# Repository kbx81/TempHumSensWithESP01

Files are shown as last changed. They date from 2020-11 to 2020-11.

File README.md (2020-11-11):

# kbx's Temperature and Humidity Sensor Board for ESP-01

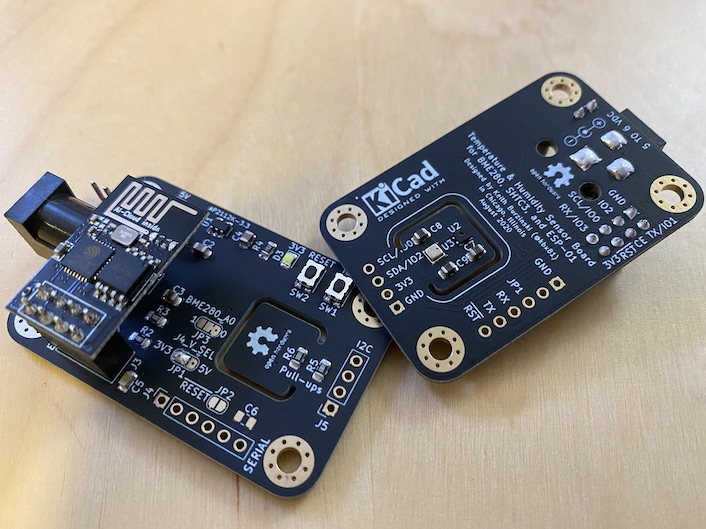
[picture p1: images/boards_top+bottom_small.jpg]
TempHumSensWithESP01


## What?

Just another environmental sensor board to plug an ESP-01 module onto.
 It was designed with [ESPHome](https://esphome.io) in mind but should work fine
 with [Tasmota](https://tasmota.github.io/docs/) or any other app, really.

## Why?

I needed a sensor board to monitor the humidity in my filament storage box.
 I was somewhat unhappy with the tiny DHT22 boards that are typically available
 on Amazon and elsewhere so I spun my own version. The dual-sensor arrangement
 allows for some redundancy -- they, in a sense, verify each other to help
 increase confidence in the readings/data they provide.

The board itself is sized to align with extra mounting holes that seem to be
 in the Prusa MK3 frame. With the help of the [spacer](BME280+SHTC3BoardMountForPrusaMK3.stl)
 I drew up, it should be possible to mount it directly to the printer's frame
 with just two M3 screws from your "spare parts" baggy. I've done this to monitor
 the temperature inside of the LACK enclosure I built for my printer with the help
 of [Home Assistant](https://www.home-assistant.io), [ESPHome](https://esphome.io)
 and [Grafana](https://grafana.com). This board can be powered from a spare 5-volt
 header that's near the top of the MK3's RAMbo board (the cable is visible in the
 pictures I've placed into the [images](images/) directory).

## How?

Please see the BoM [here](TempHumSensWithESP01.bom.csv) or
 [here](https://octopart.com/bom-tool/L01oa2CK) for a list of parts needed to
 build one. I had the PCBs fabricated by [Elecrow](https://www.elecrow.com) but
 nearly any PCB fabricator should be able to manufacture these without any issues.

The schematic and PCB were drawn in [KiCAD](https://www.kicad-pcb.org).

The BME280 is the most challenging part on this board -- the pads are on the
 underside of the device. You'll need a steady hand and either a hot air station
 or a reflow oven to solder this part to the board. The rest of the components are
 pretty easy to work with.

Note that `R7` is optional; you can use it as a pull-up resistor in the event that
 you'd like to connect a DHTxx module to the RX/GPIO3 line on the ESP-01. Why?
 Because more sensors...duh...

 ## Legal stuff and License

The circuit schematics and PCB found here are licensed under the
 [Creative Commons Attribution-ShareAlike 4.0 International License](http://creativecommons.org/licenses/by-sa/4.0/).



_Happy building!_

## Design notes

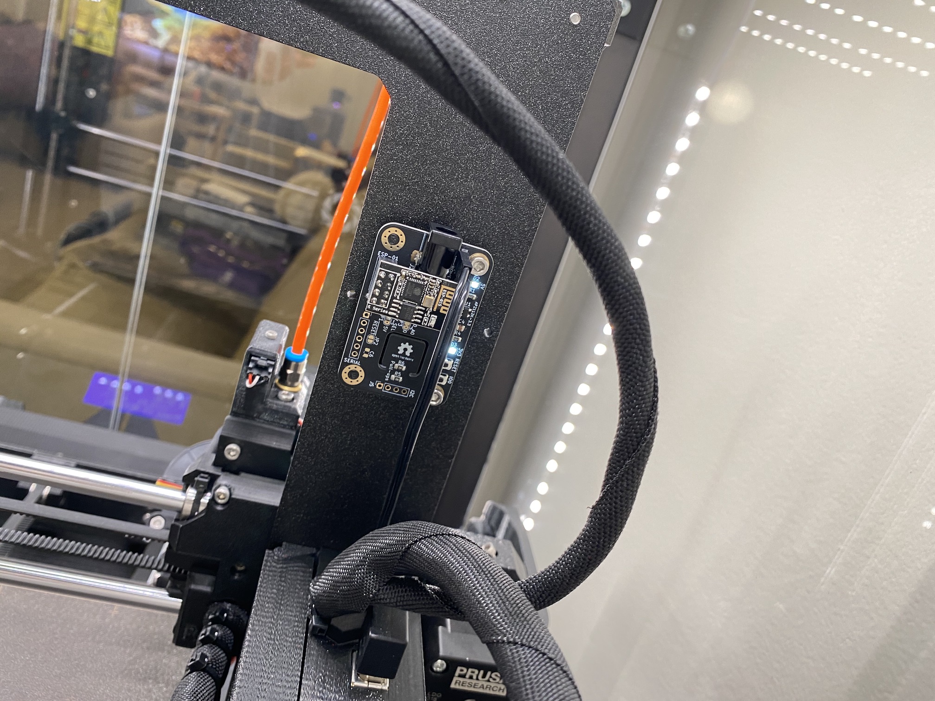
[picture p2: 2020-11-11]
images/board_on_mk3.jpg

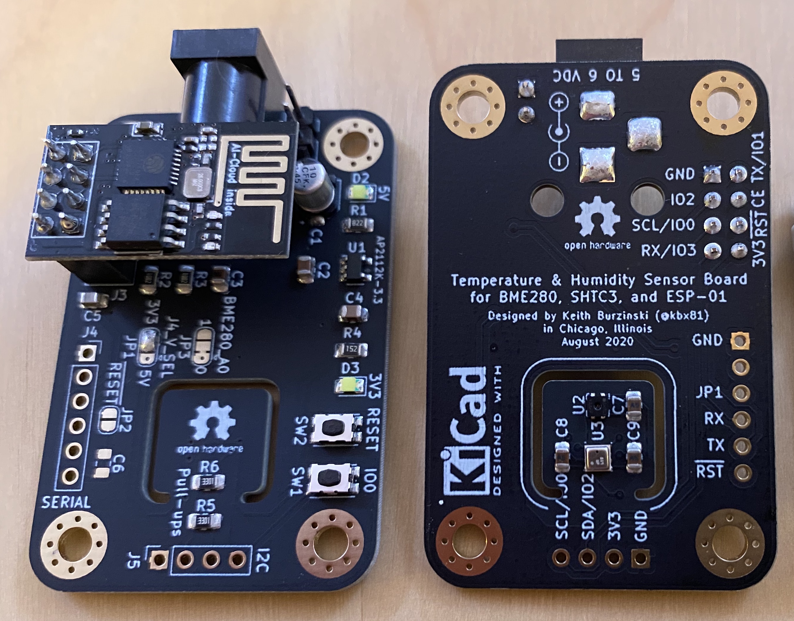
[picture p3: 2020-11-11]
images/boards_flat_top+bottom.jpg

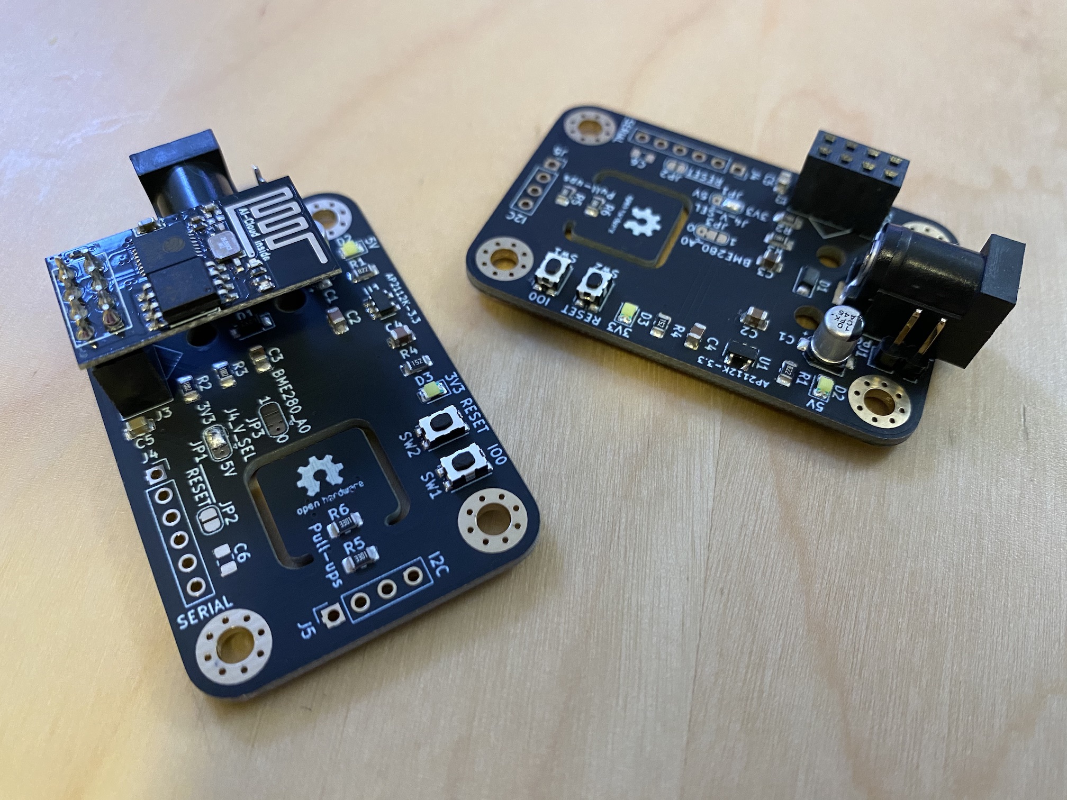
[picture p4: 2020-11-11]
images/boards_top.jpg

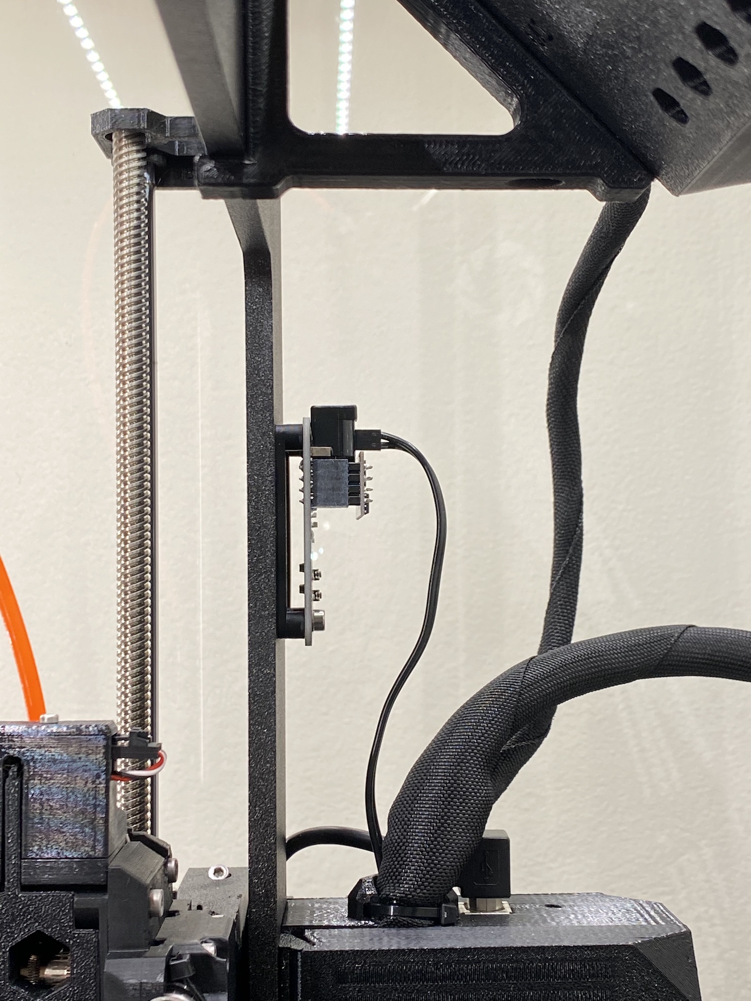
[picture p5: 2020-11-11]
images/board_on_mk3_side.jpg

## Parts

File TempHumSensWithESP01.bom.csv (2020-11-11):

Item | Qty | Reference(s) | Value | LibPart | Footprint | Datasheet | Part
1 | 1 | C1 | 10 uF | Device:CP | Capacitor_SMD:CP_Elec_4x5.8 | https://www.cde.com/resources/catalogs/AFK.pdf | AFK106M16B12T-F
2 | 2 | C2, C4 | 1 uF | Device:C | Capacitor_SMD:C_0805_2012Metric | ~ | CGA4J2X7R1C105K125AA
3 | 5 | C3, C6, C7, C8, C9 | 100 nF | Device:C | Capacitor_SMD:C_0805_2012Metric | ~ | CC0805KRX7R7BB104
4 | 1 | C5 | 10 uF | Device:C | Capacitor_SMD:C_0805_2012Metric | ~ | C2012X5R1C106M085AC
5 | 1 | D1 | MBR120 | Device:D_Schottky | Diode_SMD:D_SOD-123 | ~ | MBR120
6 | 1 | D2 | 5V | Device:LED | LED_SMD:LED_0805_2012Metric | ~ | LSM0805543V
7 | 1 | D3 | 3V3 | Device:LED | LED_SMD:LED_0805_2012Metric | ~ | LSM0805543V
11 | 1 | J2 | 5 TO 6 VDC | Connector:Barrel_Jack_Switch | Connector_BarrelJack:BarrelJack_Horizontal | ~ | 694106301002
18 | 1 | R1 | 8K2 | Device:R | Resistor_SMD:R_0805_2012Metric_Pad1.15x1.40mm_HandSolder | ~ | RT0805FRE078K2L
19 | 3 | R2, R3, R7 | 10K | Device:R | Resistor_SMD:R_0805_2012Metric_Pad1.15x1.40mm_HandSolder | ~ | RC0805FR-0710KL
20 | 1 | R4 | 1K6 | Device:R | Resistor_SMD:R_0805_2012Metric_Pad1.15x1.40mm_HandSolder | ~ | RT0805FRE071K6L
21 | 2 | R5, R6 | 3K3 | Device:R | Resistor_SMD:R_0805_2012Metric_Pad1.15x1.40mm_HandSolder | ~ | RT0805FRE073K3L
22 | 1 | SW1 | IO0 | Switch:SW_Push | Button_Switch_SMD:SW_Push_1P1T_NO_CK_KMR2 | ~ | KMR221GLFS
23 | 1 | SW2 | RESET | Switch:SW_Push | Button_Switch_SMD:SW_Push_1P1T_NO_CK_KMR2 | ~ | KMR221GLFS
24 | 1 | U1 | AP2112K-3.3 | Regulator_Linear:AP2112K-3.3 | Package_TO_SOT_SMD:SOT-23-5 | https://www.diodes.com/assets/Datasheets/AP2112.pdf | AP2112K-3.3TRG1
25 | 1 | U2 | SHTC3 | Sensor_Humidity:SHTC3 | Package_DFN_QFN:AMS_QFN-4-1EP_2x2mm_P0.95mm_EP0.7x1.6mm | https://www.sensirion.com/fileadmin/user_upload/customers/sensirion/Dokumente/0_Datasheets/Humidity/Sensirion_Humidity_Sensors_SHT1x_Datasheet.pdf | SHTC3
26 | 1 | U3 | BME280 | Sensor:BME280 | Package_LGA:Bosch_LGA-8_2.5x2.5mm_P0.65mm_ClockwisePinNumbering | https://ae-bst.resource.bosch.com/media/_tech/media/datasheets/BST-BME280-DS002.pdf | BME280

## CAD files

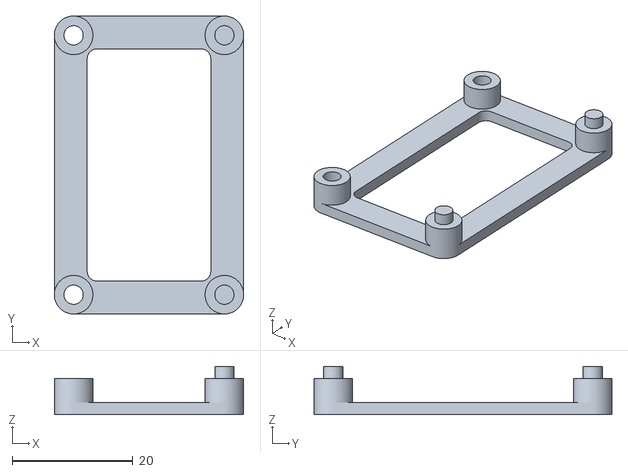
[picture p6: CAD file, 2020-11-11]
BME280+SHTC3BoardMountForPrusaMK3.stl
31.4 x 49.4 x 8.00

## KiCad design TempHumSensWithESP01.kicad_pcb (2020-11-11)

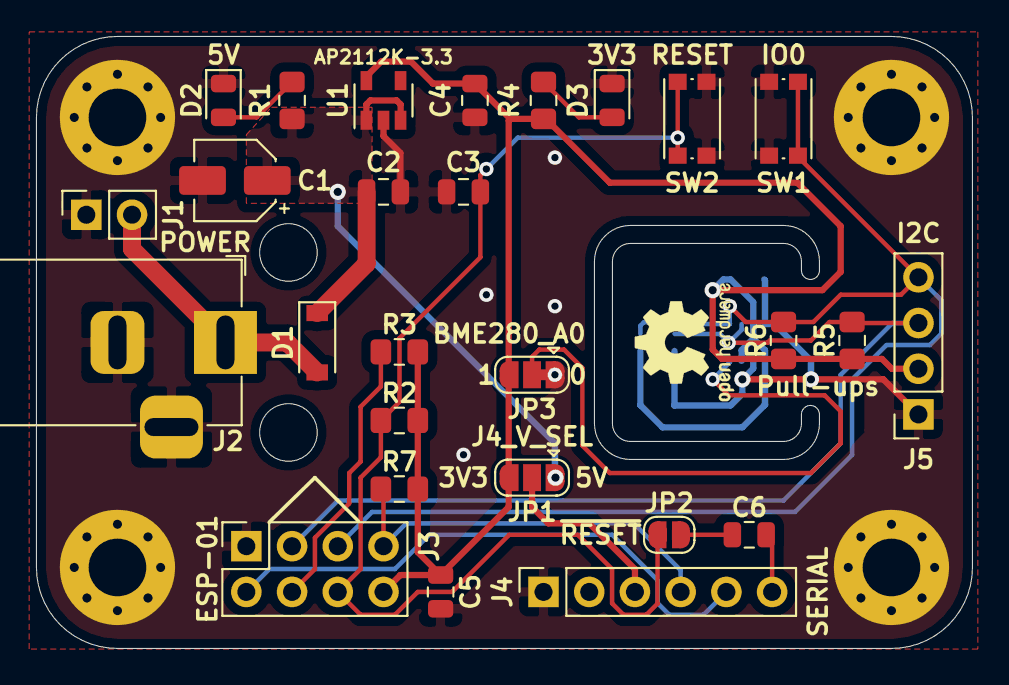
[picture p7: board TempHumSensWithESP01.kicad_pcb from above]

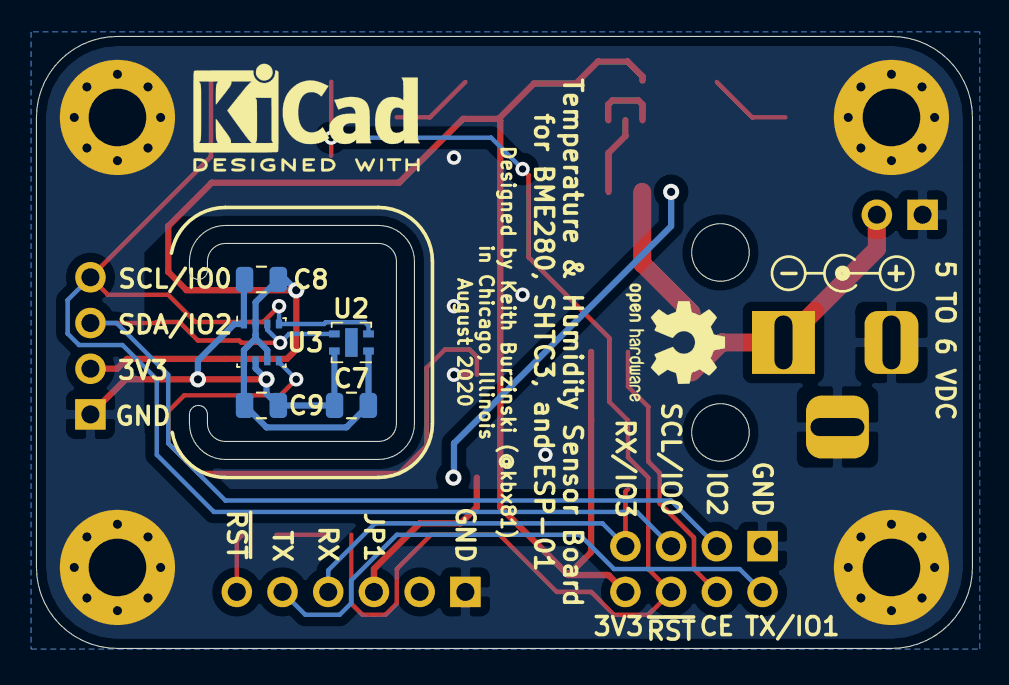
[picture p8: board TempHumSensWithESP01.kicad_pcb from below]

Board: 2 copper layers, 52.0 x 34.0 mm, 38 parts (7 on the bottom side), 16 nets.

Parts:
C1: 10 uF; CP_Elec_4x5.8
C2, C4: 1 uF; C_0805_2012Metric
C3, C6, C7, C8, C9: 100 nF; C_0805_2012Metric
C5: 10 uF; C_0805_2012Metric
D1: MBR120; D_SOD-123
D2: 5V; LED_0805_2012Metric
D3: 3V3; LED_0805_2012Metric
H1, H2, H3, H4: MountingHole_Pad; MountingHole_3.2mm_M3_Pad_Via
H5, H6: MountingHole; MountingHole_3.2mm_M3
J1: POWER; PinSocket_1x02_P2.54mm_Vertical
J2: 5 TO 6 VDC; BarrelJack_Horizontal
J3: ESP-01; PinSocket_2x04_P2.54mm_Vertical
J4: SERIAL; PinSocket_1x06_P2.54mm_Vertical
J5: I2C; PinSocket_1x04_P2.54mm_Vertical
JP1: J4_V_SEL; SolderJumper-3_P1.3mm_Open_RoundedPad1.0x1.5mm
JP2: ~RESET; SolderJumper-2_P1.3mm_Open_RoundedPad1.0x1.5mm
JP3: BME280_A0; SolderJumper-3_P1.3mm_Bridged12_RoundedPad1.0x1.5mm
R1: 8K2; R_0805_2012Metric_Pad1.15x1.40mm_HandSolder
R2, R3, R7: 10K; R_0805_2012Metric_Pad1.15x1.40mm_HandSolder
R4: 1K6; R_0805_2012Metric_Pad1.15x1.40mm_HandSolder
R5, R6: 3K3; R_0805_2012Metric_Pad1.15x1.40mm_HandSolder
SW1: IO0; SW_Push_1P1T_NO_CK_KMR2
SW2: RESET; SW_Push_1P1T_NO_CK_KMR2
U1: AP2112K-3.3; SOT-23-5
U2: SHTC3; AMS_QFN-4-1EP_2x2mm_P0.95mm_EP0.7x1.6mm
U3: BME280; Bosch_LGA-8_2.5x2.5mm_P0.65mm_ClockwisePinNumbering

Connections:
+3V3: C4.1, C5.1, C7.1, C8.1, C9.1, J3.8, J5.2, JP1.3, JP3.3, R2.2, R3.2, R4.1, R5.1, R6.1, R7.2, U1.5, U2.1, U3.2, U3.6, U3.8
+5V: C1.1, C2.1, D1.1, JP1.1, R1.1, U1.1, U1.3
/ESP_CH_EN: J3.4, R3.1
/ESP_GPIO0_SCL: J3.5, J5.4, R6.2, SW1.1, U2.2, U3.4
/ESP_GPIO1_TX: J3.2, J4.5
/ESP_GPIO2_SDA: J3.3, J5.3, R5.2, U2.3, U3.3
/ESP_GPIO3_RX: J3.7, J4.4, R7.1
/~ESP_RESET: C3.1, J3.6, JP2.2, R2.1, SW2.1
GND: C1.2, C2.2, C3.2, C4.2, C5.2, C7.2, C8.2, C9.2, D2.1, D3.1, H1.1, H2.1, H3.1, H4.1, J1.1, J2.2, J2.3, J3.1, J4.1, J5.1, JP3.1, SW1.2, SW2.2, U1.2, U2.4, U3.1, U3.7
unnamed: C6.1, JP2.1
unnamed: C6.2, J4.6
unnamed: D1.2, J1.2, J2.1
unnamed: D2.2, R1.2
unnamed: D3.2, R4.2
unnamed: J4.3, JP1.2
unnamed: JP3.2, U3.5

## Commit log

2020-11-11 Add MK3 mount
    [BME280+SHTC3BoardMountForPrusaMK3.stl]
2020-11-11 Copy, gerbers
    [TempHumSensWithESP01-B_Cu.gbr, TempHumSensWithESP01-B_Mask.gbr, TempHumSensWithESP01-B_Paste.gbr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]

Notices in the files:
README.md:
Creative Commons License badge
